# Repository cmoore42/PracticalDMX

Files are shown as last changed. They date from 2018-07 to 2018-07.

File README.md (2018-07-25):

# PracticalDMX
A battery powered standalone sACN node for remotely running on-stage practical lights.

The inspiration for this project came from a show I worked on that required lights on a moving platform.  
The lights were "practicals" - lights on stage that need to look like real world lights.
This is usually done by having the lights controlled by the lighting console, and having the console operator take
a cue to turn on the light when an actor flips a non-functional switch.
However, in this case, the lights were on moving platforms so couldn't be wired to either power or control.
The solution was a battery powered system with a 12V lead acid battery, a switch, and a 2W 12V light fixture.  
This meant that the actors had to actually flip a real switch to turn on the light.

This project is an sACN version of that.  It's a module that is powered by a 12V battery, can run 12V lights, 
but appears as an sACN node.
The lights can be completely portable, but can be controlled by a lighting console.

# Software
- Network configuration using WiFiManager
- sACN receive functionality using E131 library

# Hardware
- NodeMCU Devkit
- 0.96" I2C OLED display (From DIYMall)
- Custom PCB
- Four FQP30N06L N-Channel MOSFETs (From Sparkfun)
- Four 10K resistors
- Various connectors, headers, sockets

# Project Status
- PC Board designed and ordered
- PC Board built and tested with 12V input power
- Software done and tested, as much as possible without hardware

# To Do List
- Add code to allow for setting of universe and address offset
- Test PC board with actual 12V LED lights
- Add overcurrent protection to circuit
- Create 3D printable case

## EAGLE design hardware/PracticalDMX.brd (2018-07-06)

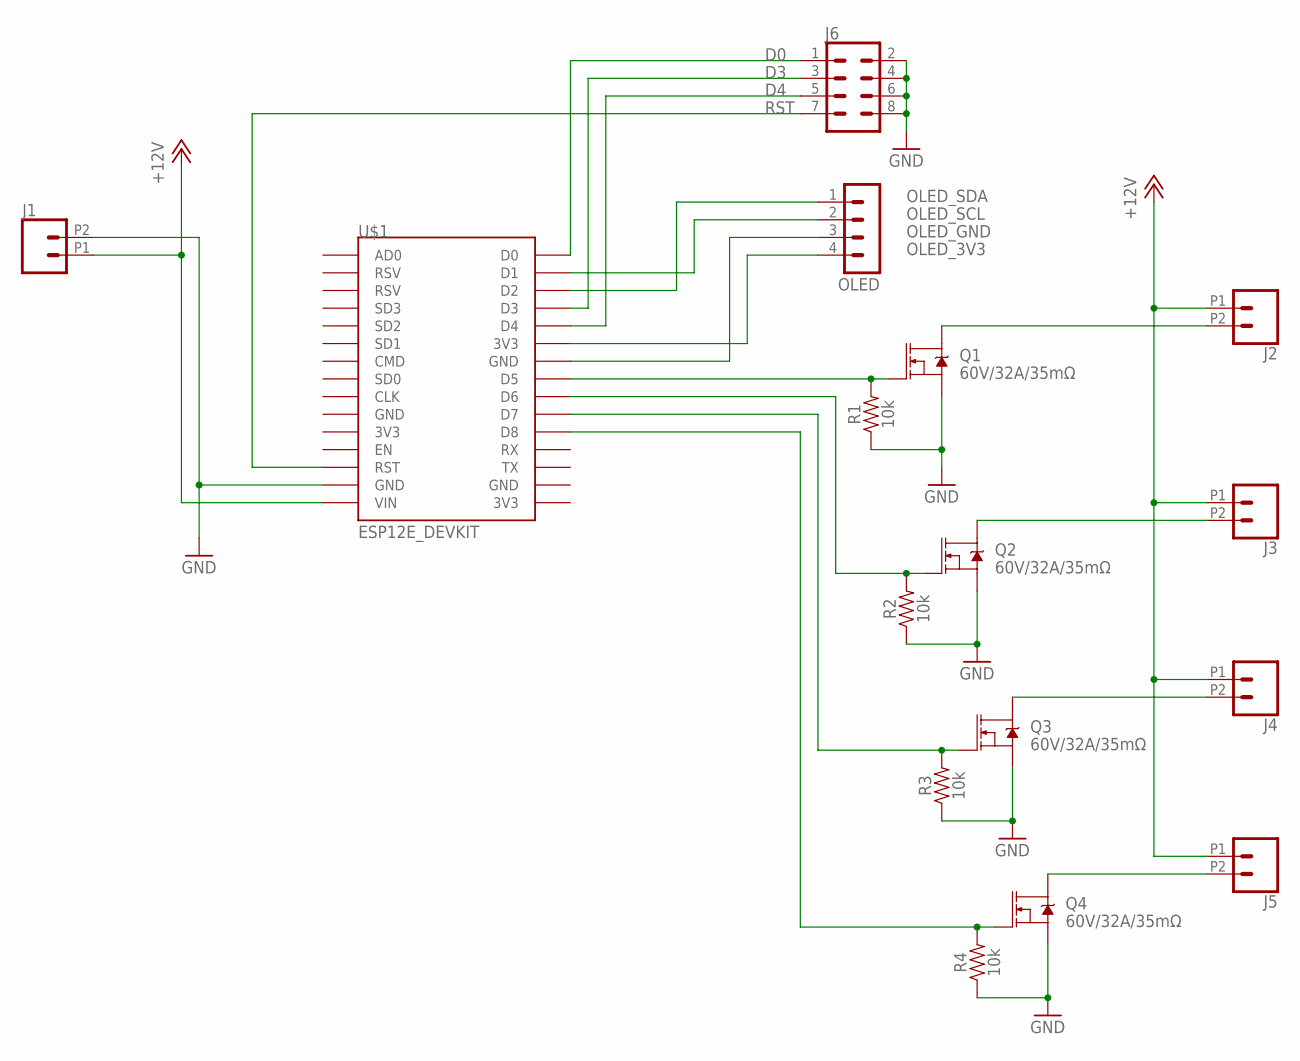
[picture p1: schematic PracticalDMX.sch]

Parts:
J1, J2, J3, J4, J5: CONN_022.54MM_SCREWTERM; 1X02_2.54_SCREWTERM
J6: CONN_04X2; 2X4
OLED: MA04-1
Q1, Q2, Q3, Q4: 60V/32A/35mΩ; TO220V
R1, R2, R3, R4: 10k; AXIAL-0.3
U$1: ESP12E_DEVKIT

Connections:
+12V: J1.P1 (1), J2.P1 (1), J3.P1 (1), J4.P1 (1), J5.P1 (1), U$1.VIN
D0: J6.1, U$1.D0
D3: J6.3, U$1.D3
D4: J6.5, U$1.D4
GND: J1.P2 (2), J6.2, J6.4, J6.6, J6.8, Q1.3 (S), Q2.3 (S), Q3.3 (S), Q4.3 (S), R1.P$1 (1), R2.P$1 (1), R3.P$1 (1), R4.P$1 (1), U$1.GND@1 (GND)
unnamed: J5.P2 (2), Q4.2 (D)
unnamed: J4.P2 (2), Q3.2 (D)
unnamed: Q1.1 (G), R1.P$2 (2), U$1.D5
unnamed: Q2.1 (G), R2.P$2 (2), U$1.D6
unnamed: Q3.1 (G), R3.P$2 (2), U$1.D7
unnamed: Q4.1 (G), R4.P$2 (2), U$1.D8
unnamed: J3.P2 (2), Q2.2 (D)
unnamed: J2.P2 (2), Q1.2 (D)
OLED_3V3: OLED.4, U$1.3V3@1 (3V3)
OLED_GND: OLED.3, U$1.GND@2 (GND)
OLED_SCL: OLED.2, U$1.D1
OLED_SDA: OLED.1, U$1.D2
RST: J6.7, U$1.RST

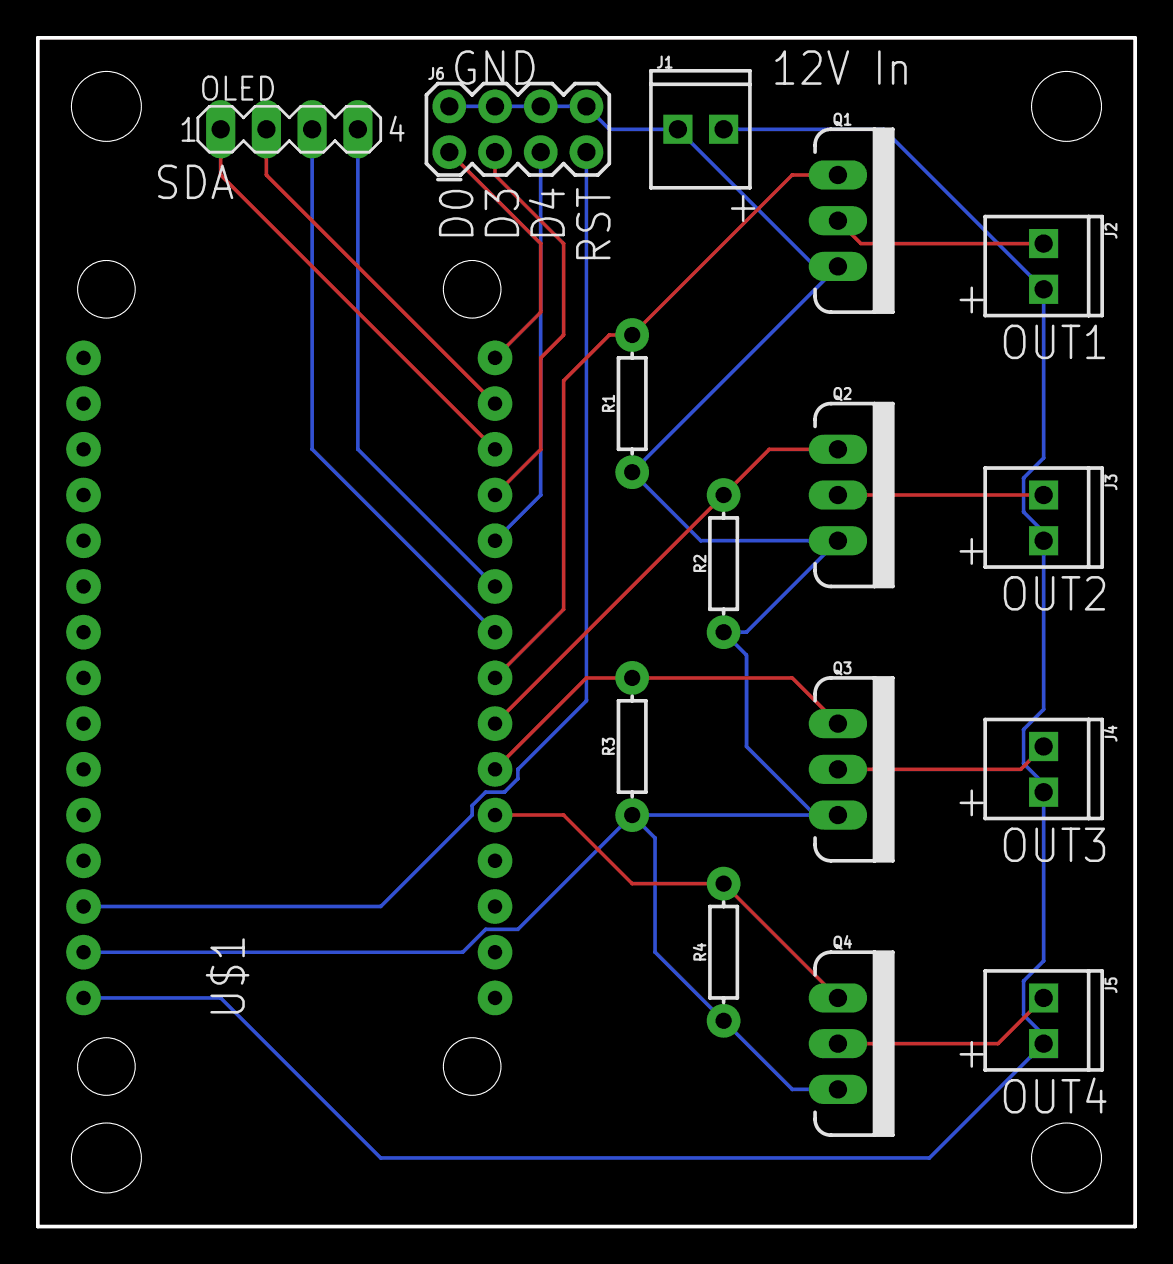
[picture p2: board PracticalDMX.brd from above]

Board: 2 copper layers, 61.0 x 66.0 mm, 16 parts (0 on the bottom side), 18 nets.

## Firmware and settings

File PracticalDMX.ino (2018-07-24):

/*
The MIT License (MIT)

Copyright (c) 2018 Chris Moore

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
Uses or is derived from:
- WiFiManager by Ken Taylor - https://github.com/kentaylor/WiFiManager 
- TickerShceulder by Toshik - https://github.com/Toshik/TickerScheduler 
- E131 by Shelby Merrick - https://github.com/forkineye/E131
*/

// WiFi and WiFiManager
#include <ESP8266WiFi.h>          // https://github.com/esp8266/Arduino
#include <ESP8266WebServer.h>
#include <DNSServer.h>
#include <WiFiManager.h>          // https://github.com/kentaylor/WiFiManager

// OLED Display stuff
#include <SPI.h>
#include <Wire.h>
#include <Adafruit_GFX.h>         // Library Manager
#include <Adafruit_SSD1306.h>     // Library Manager

// sACN
#include <E131.h>                 // Library Manager

// Timer
#include <TickerScheduler.h>      // https://github.com/Toshik/TickerScheduler

const int PIN_LED = LED_BUILTIN; 

/*Trigger for inititating config mode */
const int TRIGGER_PIN = D3; // Flash button on NodeMCU

// Adafruit_SSD1306 expects a reset pin, but the OLED I'm using doesn't
// have one.  Using the LED pin instead.
#define OLED_RESET LED_BUILTIN
Adafruit_SSD1306 display(OLED_RESET);

// sACN related items
E131 e131;
int fps = 0;
int frames_since_last_tick = 0;
int data_loss_counter = 0;    // Number of seconds since we last saw a frame
#define DATA_LOSS_TIMEOUT 5   // After this many seconds of no data all channels go to 0
int universe = 1;
int base_address = 1;

// Timer related items
TickerScheduler ts(1);
void tick_handler(void *);

// REST server
#define REST_PORT 80
ESP8266WebServer restServer(REST_PORT);
void rest_get_universe();
void rest_put_universe();
void rest_get_address();
void rest_put_address();
void handle_not_found();
void handle_root();

// Number of channels supported by the hardware
#define NUM_CHANS 4
uint8_t levels[NUM_CHANS];
uint8_t output_pins[NUM_CHANS];

// Overall state
#define STATE_UNKNOWN -1    // Startup state
#define STATE_CONNECTING 0  // Trying to connect to WiFi
#define STATE_CONFIG 1      // In AP mode, presenting the config page
#define STATE_CONNECTED 2   // Connected to WiFi
#define STATE_FAILED 3      // In a failed state
#define STATE_DATALOSS 4    // Connected but no sACN received 
int state = STATE_UNKNOWN;

void setup() {
  int i;

  output_pins[0] = D5;
  output_pins[1] = D6;
  output_pins[2] = D7;
  output_pins[3] = D8;
  for (i=0; i<NUM_CHANS; i++) {
    levels[i] = 0;
    pinMode(output_pins[i], OUTPUT);
    analogWrite(output_pins[i], 0);
  }

  pinMode(PIN_LED, OUTPUT);
  Serial.begin(115200);
  Serial.println("\n Starting");

  // Initialize the display
  display.begin(SSD1306_SWITCHCAPVCC, 0x3c);
  display.setTextSize(1);
  display.setTextColor(WHITE);
  
  updateDisplay();
  
  // WiFi.printDiag(Serial);
 
  if (WiFi.SSID()==""){
    Serial.println("We haven't got any access point credentials, so get them now");   
    state_change(STATE_CONFIG);
  } else {
    Serial.print("Trying to connect to ");
    Serial.println(WiFi.SSID());
    state_change(STATE_CONNECTING);
    updateDisplay();
    WiFi.mode(WIFI_STA); // Force to station mode because if device was switched off while in access point mode it will start up next time in access point mode.
    unsigned long startedAt = millis();
    int connRes = WiFi.waitForConnectResult();
    float waited = (millis()- startedAt);
    Serial.print("After waiting ");
    Serial.print(waited/1000);
    Serial.print(" secs in setup() connection result is ");
    Serial.println(connRes);
  }
  pinMode(TRIGGER_PIN, INPUT_PULLUP);

  /*
   * Posibilities at this point:
   * - We're in STATE_CONNECTING and we've connected
   * - We're in STATE_CONNECTING and we're not connected
   * - We're in STATE_CONFIG
   */

  if (state == STATE_CONNECTING) {
    if ((WiFi.status()!=WL_CONNECTED)) {
      // Sometimes it seems to go from DISCONNECTED to FAILED and then to CONNECTED.
      // We'll wait up to 10 seconds for it to connect
      int iter = 10;
      while(iter > 0) {
        int connRes = WiFi.status();
        Serial.print("Status is ");
        Serial.println(connRes);
        if (connRes == WL_CONNECTED) {
          state_change(STATE_CONNECTED);
          break;
        }
        delay(1000);
        --iter;
      }
      if (state != STATE_CONNECTED) {
        /* After 10 seconds we're still not connected */
        state_change(STATE_CONFIG);
      }
    } else {
      /* We were in STATE_CONNECTING and now we're connected */
      state_change(STATE_CONNECTED);
    }
  }
  
  if (state == STATE_CONNECTED) {
    Serial.print("local ip: ");
    Serial.println(WiFi.localIP());
  }
  updateDisplay();

  ts.add(0, 1000, tick_handler, NULL);
}


void loop() {
  // If the TRIGGER_PIN goes low, enter CONFIG mode
  if (digitalRead(TRIGGER_PIN) == LOW) {
     state_change(STATE_CONFIG);
  }

  if (state == STATE_CONFIG) {
     Serial.println("Configuration portal requested.");
     updateDisplay();
    //Local intialization. Once its business is done, there is no need to keep it around
    WiFiManager wifiManager;

    //sets timeout in seconds until configuration portal gets turned off.
    //If not specified device will remain in configuration mode until
    //switched off via webserver or device is restarted.
    //wifiManager.setConfigPortalTimeout(600);

    //it starts an access point 
    //and goes into a blocking loop awaiting configuration
    if (!wifiManager.startConfigPortal()) {
      state_change(STATE_FAILED);
      Serial.println("Not connected to WiFi but continuing anyway.");
    } else {
      //if you get here you have connected to the WiFi
      state_change(STATE_CONNECTED);
      updateDisplay();
      Serial.println("connected...yeey :)");
      Serial.print("local ip: ");
      Serial.println(WiFi.localIP());
    }
    ESP.reset(); // This is a bit crude. For some unknown reason webserver can only be started once per boot up 
    // so resetting the device allows to go back into config mode again when it reboots.
    delay(5000);
  }

  
  /* Parse a packet */
  uint16_t num_channels = e131.parsePacket();
    
  /* Process channel data if we have it */
  /*
   * data[0] is DMX address 1, etc
   * We are interested in values for "base_address" through "base_address + NUM_CHAN - 1"
   * eg:  if base_address is 20 and NUM_CHAN is 4, we want DMX addresses 20-23
   * 
   * num_channels is how many channels of DMX data we got in a packet
   * 
   * if (num_channels < base_address) then we didn't get data for the our lowest address
   * if (num_channels > (base_address + NUM_CHAN -1)) then we got more than we need
   * 
   */
   
  if (num_channels >= base_address) {
      ++frames_since_last_tick;
      int first = base_address - 1;
      int last = base_address + NUM_CHANS - 1;
      if (last >= num_channels) {
        last = num_channels-1;
      }
      int j=0;
      for (int i=first; i < last; i++) {
        levels[j] = e131.data[i];
        ++j;
      }
      updateLevels();
  }

  // Let the TickerScheduler do its thing
  ts.update();

  // Handle any REST requests
  restServer.handleClient();
}

/**
 * Helper routine to clear the screen, set the cursor position to
 * the top left, and display a line of text.
 */
void displayPrint(char *text) {
  display.clearDisplay();
  display.setCursor(0,0);
  display.println(text);
}

/**
 * Called when any level changes, to update the PWM output values
 * Also updates the display
 */
void updateLevels() {
  int i;

  for (i=0; i<NUM_CHANS; i++) {
    analogWrite(output_pins[i], levels[i] << 2); // NodeMCU supports analog values of 0-1023
  }

  updateDisplay();
}

/**
 * Update the display based on the current state.
 * This should be the only place that anything is written to
 * the display.
 */
void updateDisplay() {
  int i;

  switch(state) {
    case STATE_UNKNOWN:
      displayPrint("Initializing...");
      display.display();
      break;
    case STATE_CONFIG:
      displayPrint("Config Mode");
      display.display();
      break;
    case STATE_CONNECTING:
      displayPrint("Connecting...");
      display.display();
      break;
    case STATE_FAILED:
      displayPrint("WiFi connection failed.");
      display.display();
      break;
    case STATE_CONNECTED:
      displayPrint("Connected");
      display.println(WiFi.localIP());
      for (i=0; i<NUM_CHANS; i++) {
        display.print("Ch ");
        display.print(universe);
        display.print("/");
        display.print(base_address+i);
        display.print(": ");
        display.println(levels[i]);
      }
      display.print("FPS: ");
      display.println(fps);
      display.display();
      break;
    case STATE_DATALOSS:
      displayPrint("No Data");
      display.println(WiFi.localIP());
      for (i=0; i<NUM_CHANS; i++) {
        display.print("Ch ");
        display.print(universe);
        display.print("/");
        display.print(base_address+i);
        display.print(": ");
        display.println(levels[i]);
      }
      display.display();
      break;
    default:
      displayPrint("???");
      display.display();
      break;
  }

}

/**
 * tick_handler runs every second.
 * It has two jobs - count frames per second, and check for data loss
 */
void tick_handler(void  *arg) {
  fps = frames_since_last_tick;
  if (fps == 0) {
    // No frames in the last second
    ++data_loss_counter;
    if ((data_loss_counter > DATA_LOSS_TIMEOUT) && (state == STATE_CONNECTED)) {
      // No frames in the last DATA_LOSS_TIMEOUT seconds, set all levels to 0
      int i;
      state_change(STATE_DATALOSS);
      for (i=0; i<NUM_CHANS; i++) {
        levels[i] = 0;
      }
      updateLevels();
    }
  } else {
    data_loss_counter = 0;
    if (state == STATE_DATALOSS) {
      state_change(STATE_CONNECTED);
    }
  }
  frames_since_last_tick = 0;
  updateDisplay();
}

/**
 * Helper function to go to a new state.
 */
void state_change(int new_state)
{
  int old_state = state;
  Serial.print("Changing from state ");
  Serial.print(old_state);
  Serial.print(" to state ");
  Serial.println(new_state);

  /* Trun on the LED if we're entering CONFIG mode, otherwise turn it off */
  if (new_state == STATE_CONFIG) {
    digitalWrite(PIN_LED, LOW);
  } else {
    digitalWrite(PIN_LED, HIGH);
  }

  /*  If we just connected, start the E13.1 processing - unless this was
   *  just a transition from DATALOSS to CONNECTED, in which case E13.1
   *  was already running.
   */
  if ((new_state == STATE_CONNECTED) && (old_state != STATE_DATALOSS)) {
    /* Start the E13.1 listener */
    e131.begin(E131_MULTICAST, universe);

    /* Start the REST listener */
    restServer.on("/universe", HTTP_GET, rest_get_universe);
    restServer.on("/universe", HTTP_PUT, rest_put_universe);
    restServer.on("/address", HTTP_GET, rest_get_address);
    restServer.on("/address", HTTP_PUT, rest_put_address);
    restServer.onNotFound(handle_not_found);
    restServer.on("/", handle_root);
    restServer.begin();
    Serial.print("REST server started on port ");
    Serial.println(REST_PORT);
  }
  
  state = new_state; 
}

void rest_get_universe()
{
  String body = String(universe);
  restServer.send(200, "text/plain", body);
}

void rest_put_universe()
{
  
}

void rest_get_address()
{
  String body = String(base_address);
  restServer.send(200, "text/plain", body);  
}

void rest_put_address()
{
  
}

void handle_root()
{
  restServer.send(200, "text/plain", "Root");
}

void handle_not_found()
{
  String message = "File Not Found\n\n";
  message += "URI: ";
  message += restServer.uri();
  message += "\nMethod: ";
  message += (restServer.method() == HTTP_GET) ? "GET" : "POST";
  message += "\nArguments: ";
  message += restServer.args();
  message += "\n";
  for (uint8_t i = 0; i < restServer.args(); i++) {
    message += " " + restServer.argName(i) + ": " + restServer.arg(i) + "\n";
  }
  restServer.send(404, "text/plain", message); 
}

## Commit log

2018-07-06 Initial checkin of code, schematic, and board layout.
    [PracticalDMX.brd, PracticalDMX.sch]
2018-07-13 Cleaned up some of the state machine code. Moved some functionality to the state_change() code. For example, enabling the E13.1 listener now happens when we change state to CONNECTED. Same with the L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
2018-07-13 Removed a couple of debug prints.
2018-07-24 Fixed logic when configuring for the first time. The logic was incorrect for the case where there was no WiFi data at all.
    [PracticalDMX.ino]

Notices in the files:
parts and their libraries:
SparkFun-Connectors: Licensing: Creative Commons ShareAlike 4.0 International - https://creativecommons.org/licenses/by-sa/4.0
